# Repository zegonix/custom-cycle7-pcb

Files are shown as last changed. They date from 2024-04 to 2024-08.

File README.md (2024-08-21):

This repository holds the design sources for a custom PCB and plate for the cycle 7 by TKD. I ordered a prototype and got that working but I do not guarantee anything.

***Note that I used a 12 MHz oscillator instead of an 8 MHz which would be QMKs default frequency for the STM32F401. That is no problem, but requires a little extra configuration. If you don't fancy that, change the oscillator circuit to 8 MHz.***

***Also the design replaces the standard 6.25u spacebar with a 1.25u key, a 2.75u key and a 2.25u key (in this order from the left). Very few keycap sets come with a 1.25 spacebar key, so you might want to change the design to use a different spacebar configuration. If you do that you also need to adjust the plate. If you plan to use the original plate of the cycle 7 you need to change the pcb design to a default 6.25u spacebar.***

Why make my own pcb for the cycle 7? Bootloader on TKD's PCB ~~is shit~~ does not comply with my requirements. Also the firmware is proprietary.

What about this PCB? Sources are here and free to use however you want. **However use at your own risk, I do not guarantee any of this to be functional**
The QMK configuration for the keyboard is available at [zegonix/zegonix-qmk-configs/zegonix/cycle7](https://github.com/zegonix/zegonix-qmk-configs). Follow the steps described in the readme file to link the folder into your local qmk repository and build the firmware.

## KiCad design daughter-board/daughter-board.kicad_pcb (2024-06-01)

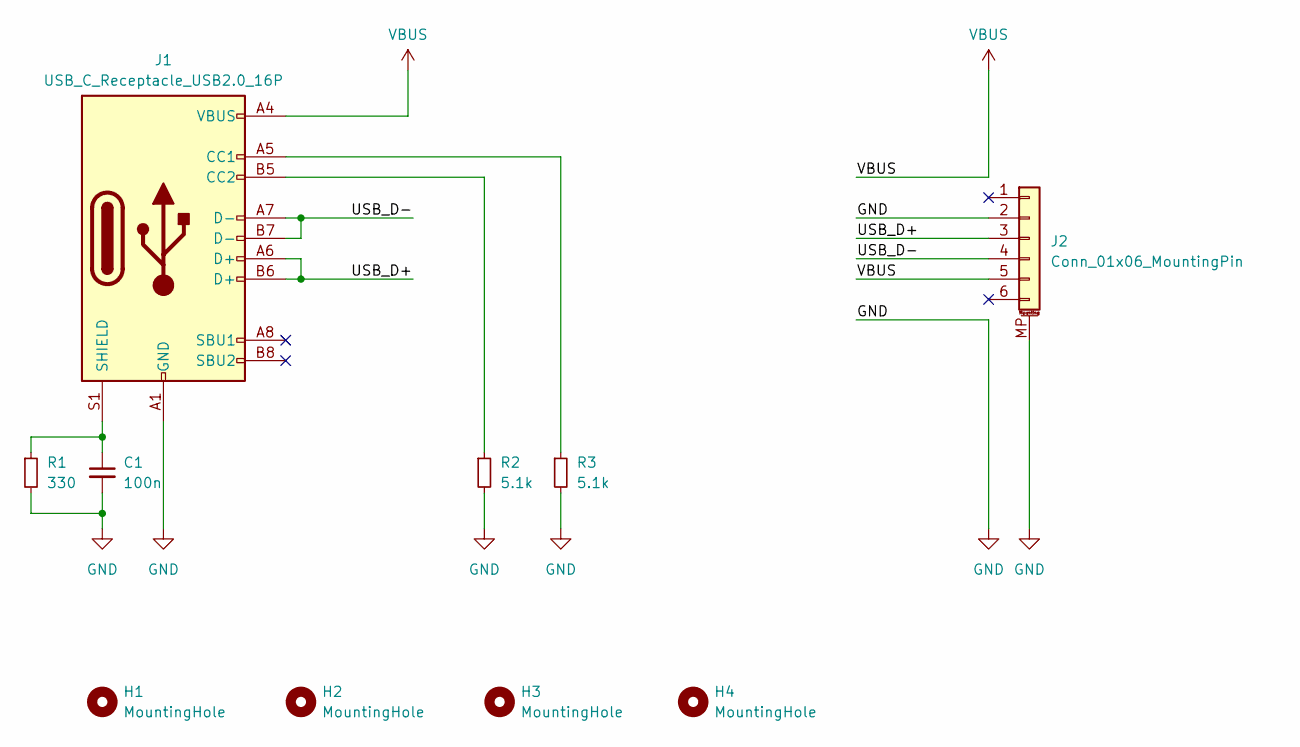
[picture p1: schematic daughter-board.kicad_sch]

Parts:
C1: 100n; C_0603_1608Metric
H1, H2, H3, H4: MountingHole; MountingHole_2.2mm_M2
J1: USB_C_Receptacle_USB2.0_16P; USB_C_Receptacle_HRO_TYPE-C-31-M-12
J2: Conn_01x06_MountingPin; JST_SH_SM06B-SRSS-TB_1x06-1MP_P1.00mm_Horizontal
R1: 330; R_0603_1608Metric
R2, R3: 5.1k; R_0603_1608Metric

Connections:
/USB_D+: J1.A6 (D+), J1.B6 (D+), J2.3
/USB_D-: J1.A7 (D-), J1.B7 (D-), J2.4
GND: C1.2, J1.A1 (GND), J1.A12 (GND), J1.B1 (GND), J1.B12 (GND), J2.2, J2.MP (MountPin), R1.2, R2.2, R3.2
unnamed: J1.A5 (CC1), R3.1
unnamed: J1.B5 (CC2), R2.1
unnamed: C1.1, J1.S1 (SHIELD), R1.1
VBUS: J1.A4 (VBUS), J1.A9 (VBUS), J1.B4 (VBUS), J1.B9 (VBUS), J2.5

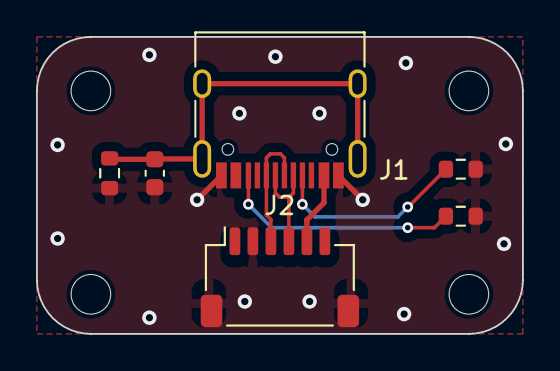
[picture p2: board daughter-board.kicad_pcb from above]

Board: 2 copper layers, 27.0 x 16.5 mm, 10 parts (0 on the bottom side), 7 nets.

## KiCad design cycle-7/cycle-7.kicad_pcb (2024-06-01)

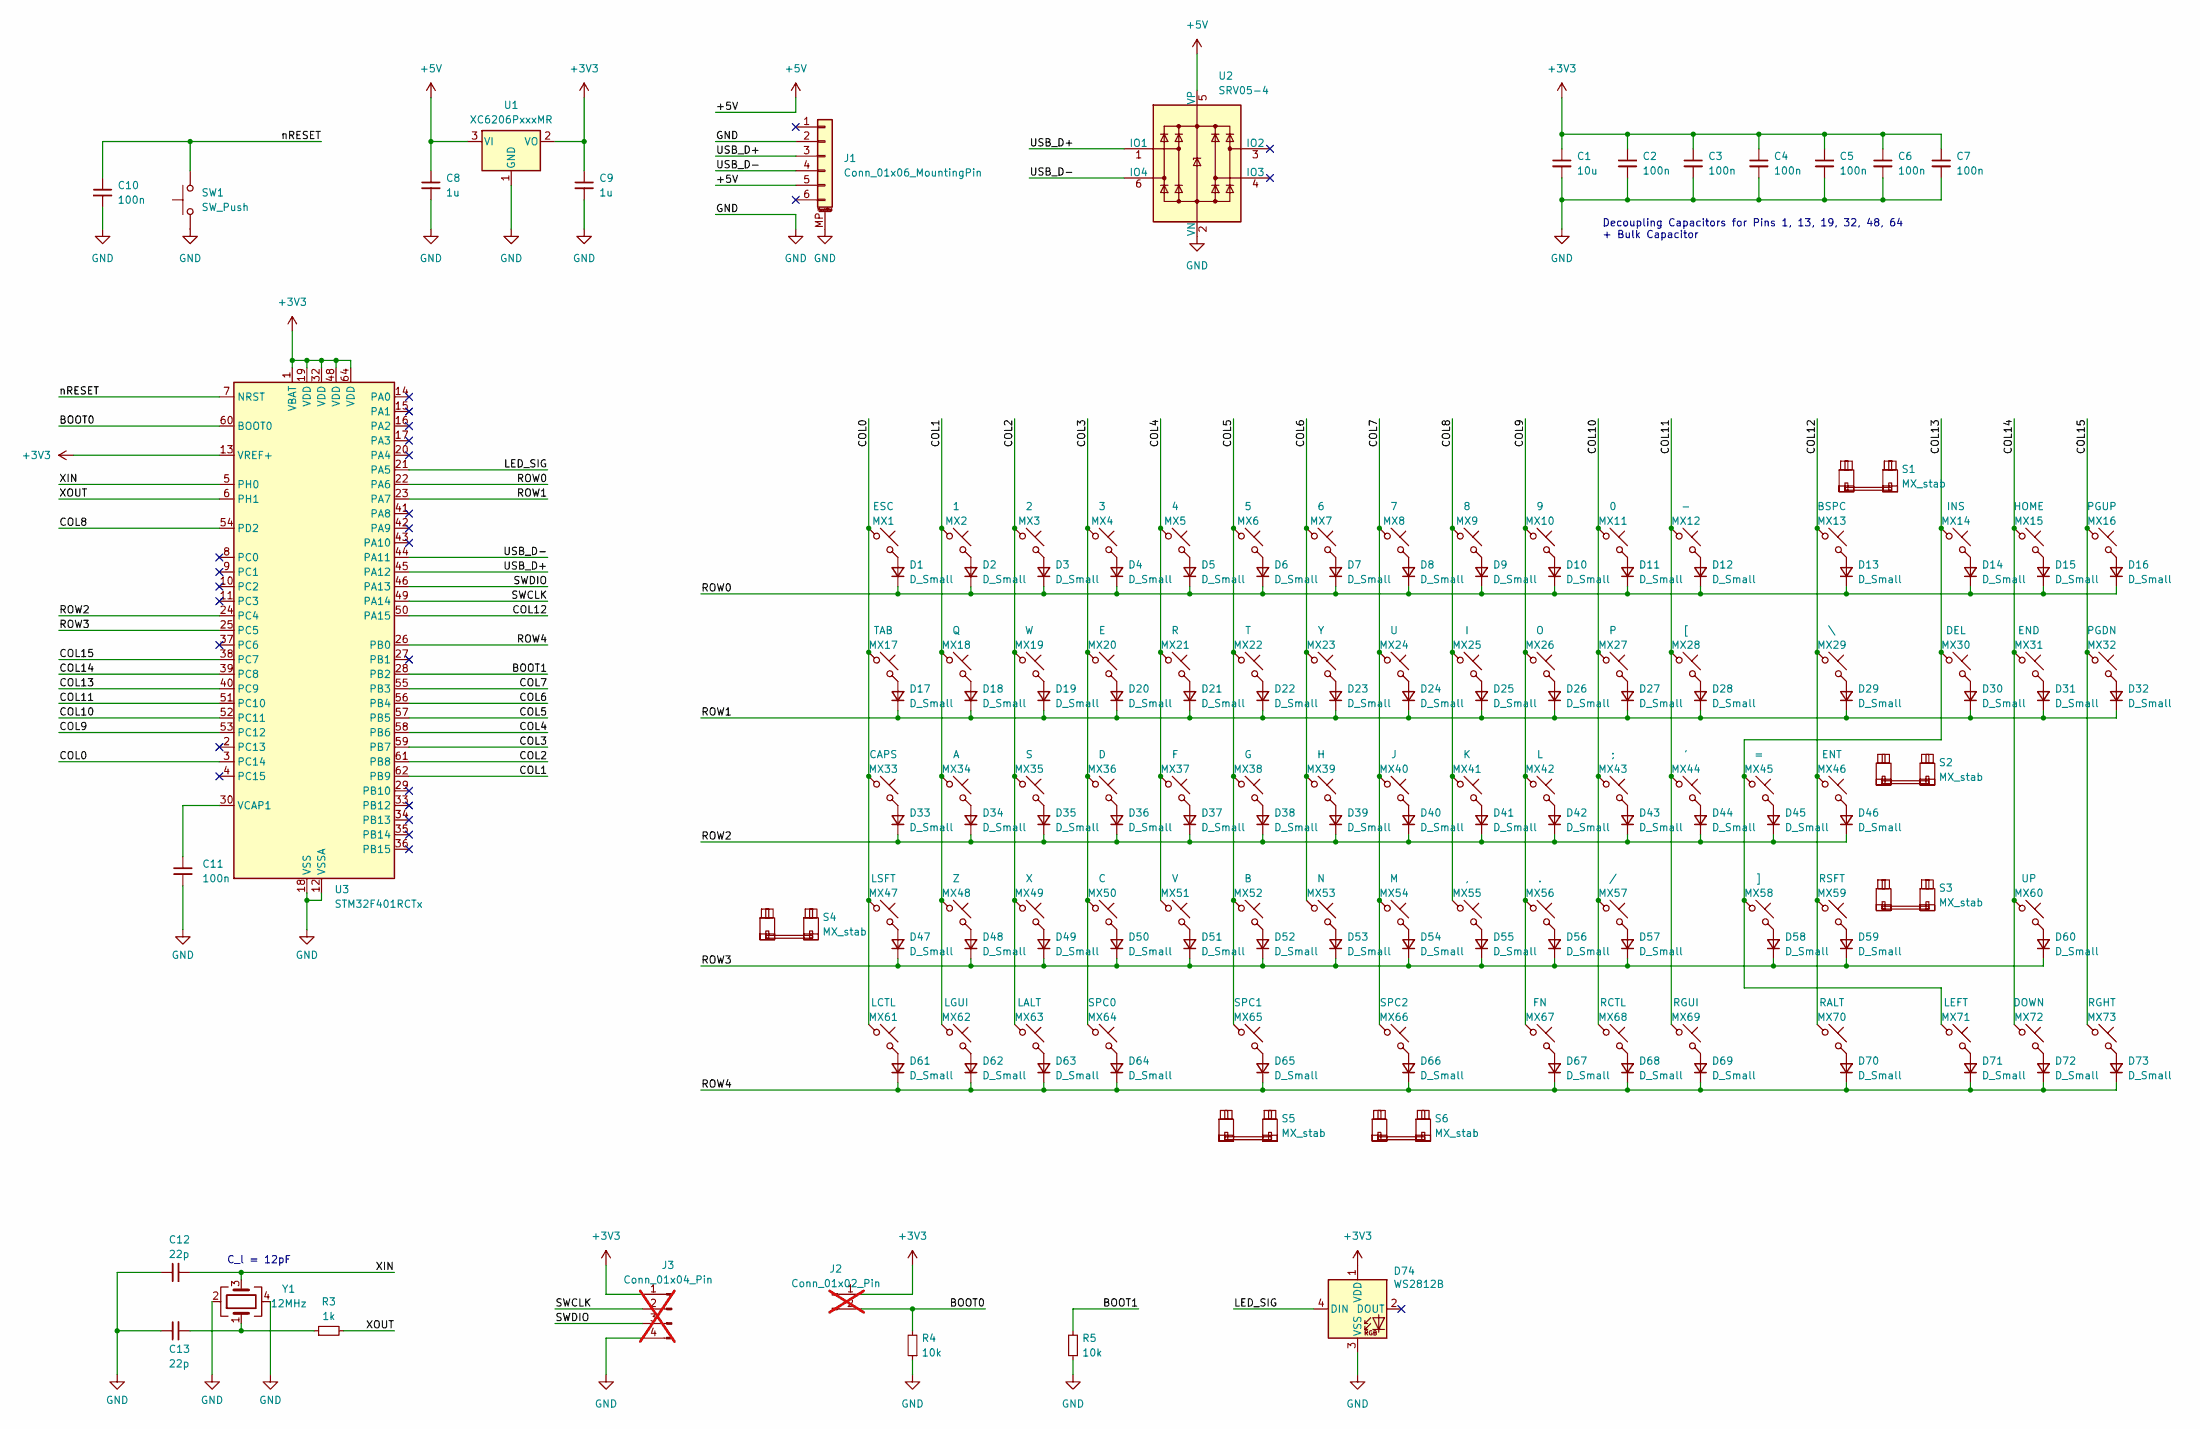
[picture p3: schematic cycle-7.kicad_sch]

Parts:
C1: 10u; C_0603_1608Metric
C2, C3, C4, C5, C6, C7, C10, C11: 100n; C_0603_1608Metric
C8, C9: 1u; C_0603_1608Metric
C12, C13: 22p; C_0603_1608Metric
D1, D2, D3, D4, D5, D6, D7, D8, D9, D10, D11, D12, D13, D14, D15, D16, D17, D18, D19, D20, D21, D22, D23, D24, D25, D26, D27, D28, D29, D30, D31, D32, D33, D34, D35, D36, D37, D38, D39, D40, D41, D42, D43, D44, D45, D46, D47, D48, D49, D50, D51, D52, D53, D54, D55, D56, D57, D58, D59, D60, D61, D62, D63, D64, D65, D66, D67, D68, D69, D70, D71, D72, D73: D_Small; D_SOD-123
D74: WS2812B; SK6812MINI-E_3.2x2.8_reverse_mount
J1: Conn_01x06_MountingPin; JST_SH_SM06B-SRSS-TB_1x06-1MP_P1.00mm_Horizontal
J2: Conn_01x02_Pin; PinHeader_1x02_P2.54mm_Vertical; not fitted
J3: Conn_01x04_Pin; PinHeader_1x04_P2.54mm_Vertical; not fitted
MX1, MX2, MX3, MX4, MX5, MX6, MX7, MX8, MX9, MX10, MX11, MX12, MX13, MX14, MX15, MX16, MX18, MX19, MX20, MX21, MX22, MX23, MX24, MX25, MX26, MX27, MX28, MX30, MX31, MX32, MX34, MX35, MX36, MX37, MX38, MX39, MX40, MX41, MX42, MX43, MX44, MX45, MX46, MX47, MX48, MX49, MX50, MX51, MX52, MX53, MX54, MX55, MX56, MX57, MX58, MX59, MX60, MX65, MX66, MX71, MX72, MX73: MX_SW_HS; SW_MX_HS_1u
MX17, MX29: MX_SW_HS; SW_MX_HS_1.5u
MX33: MX_SW_HS; SW_MX_HS_1.75u
MX61, MX62, MX63, MX64, MX67, MX68, MX69, MX70: MX_SW_HS; SW_MX_HS_1.25u
R3: 1k; R_0603_1608Metric
R4, R5: 10k; R_0603_1608Metric
S1: MX_stab; STAB_MX_P_2u
S2, S4, S6: MX_stab; STAB_MX_P_2.25u
S3, S5: MX_stab; STAB_MX_P_2.75u
SW1: SW_Push; SW_SPST_TL3342
U1: XC6206PxxxMR; SOT-23-3
U2: SRV05-4; SOT-23-6-routable
U3: STM32F401RCTx; LQFP-64_10x10mm_P0.5mm
Y1: 12MHz; Crystal_SMD_3225-4Pin_3.2x2.5mm

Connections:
+3V3: C1.1, C2.1, C3.1, C4.1, C5.1, C6.1, C7.1, C9.1, D74.1 (VDD), J2.1, J3.1, U1.2 (VO), U3.1 (VBAT), U3.13 (VREF+), U3.19 (VDD), U3.32 (VDD), U3.48 (VDD), U3.64 (VDD)
+5V: C8.1, J1.5, U1.3 (VI), U2.5 (VP)
/BOOT0: J2.2, R4.2, U3.60 (BOOT0)
/BOOT1: R5.2, U3.28 (PB2)
/COL0: MX1.1, MX17.1, MX33.1, MX47.1, MX61.1, U3.3 (PC14)
/COL1: MX2.1, MX18.1, MX34.1, MX48.1, MX62.1, U3.62 (PB9)
/COL2: MX3.1, MX19.1, MX35.1, MX49.1, MX63.1, U3.61 (PB8)
/COL3: MX4.1, MX20.1, MX36.1, MX50.1, MX64.1, U3.59 (PB7)
/COL4: MX5.1, MX21.1, MX37.1, MX51.1, U3.58 (PB6)
/COL5: MX6.1, MX22.1, MX38.1, MX52.1, MX65.1, U3.57 (PB5)
/COL6: MX7.1, MX23.1, MX39.1, MX53.1, U3.56 (PB4)
/COL7: MX8.1, MX24.1, MX40.1, MX54.1, MX66.1, U3.55 (PB3)
/COL8: MX9.1, MX25.1, MX41.1, MX55.1, U3.54 (PD2)
/COL9: MX10.1, MX26.1, MX42.1, MX56.1, MX67.1, U3.53 (PC12)
/COL10: MX11.1, MX27.1, MX43.1, MX57.1, MX68.1, U3.52 (PC11)
/COL11: MX12.1, MX28.1, MX44.1, MX69.1, U3.51 (PC10)
/COL12: MX13.1, MX29.1, MX46.1, MX59.1, MX70.1, U3.50 (PA15)
/COL13: MX14.1, MX30.1, MX45.1, MX58.1, MX71.1, U3.40 (PC9)
/COL14: MX15.1, MX31.1, MX60.1, MX72.1, U3.39 (PC8)
/COL15: MX16.1, MX32.1, MX73.1, U3.38 (PC7)
/LED_SIG: D74.4 (DIN), U3.21 (PA5)
/ROW0: D1.1 (K), D2.1 (K), D3.1 (K), D4.1 (K), D5.1 (K), D6.1 (K), D7.1 (K), D8.1 (K), D9.1 (K), D10.1 (K), D11.1 (K), D12.1 (K), D13.1 (K), D14.1 (K), D15.1 (K), D16.1 (K), U3.22 (PA6)
/ROW1: D17.1 (K), D18.1 (K), D19.1 (K), D20.1 (K), D21.1 (K), D22.1 (K), D23.1 (K), D24.1 (K), D25.1 (K), D26.1 (K), D27.1 (K), D28.1 (K), D29.1 (K), D30.1 (K), D31.1 (K), D32.1 (K), U3.23 (PA7)
/ROW2: D33.1 (K), D34.1 (K), D35.1 (K), D36.1 (K), D37.1 (K), D38.1 (K), D39.1 (K), D40.1 (K), D41.1 (K), D42.1 (K), D43.1 (K), D44.1 (K), D45.1 (K), D46.1 (K), U3.24 (PC4)
/ROW3: D47.1 (K), D48.1 (K), D49.1 (K), D50.1 (K), D51.1 (K), D52.1 (K), D53.1 (K), D54.1 (K), D55.1 (K), D56.1 (K), D57.1 (K), D58.1 (K), D59.1 (K), D60.1 (K), U3.25 (PC5)
/ROW4: D61.1 (K), D62.1 (K), D63.1 (K), D64.1 (K), D65.1 (K), D66.1 (K), D67.1 (K), D68.1 (K), D69.1 (K), D70.1 (K), D71.1 (K), D72.1 (K), D73.1 (K), U3.26 (PB0)
/SWCLK: J3.2, U3.49 (PA14)
/SWDIO: J3.3, U3.46 (PA13)
/USB_D+: J1.3, U2.1 (IO1), U3.45 (PA12)
/USB_D-: J1.4, U2.6 (IO4), U3.44 (PA11)
/XIN: C12.2, U3.5 (PH0), Y1.3
/XOUT: R3.2, U3.6 (PH1)
/nRESET: C10.1, SW1.2, U3.7 (NRST)
GND: C1.2, C2.2, C3.2, C4.2, C5.2, C6.2, C7.2, C8.2, C9.2, C10.2, C11.2, C12.1, C13.1, D74.3 (VSS), J1.2, J1.MP (MountPin), J3.4, R4.1, R5.1, SW1.1, U1.1 (GND), U2.2 (VN), U3.12 (VSSA), U3.18 (VSS), U3.31 (VSS), U3.47 (VSS), U3.63 (VSS), Y1.2, Y1.4
unnamed: C13.2, R3.1, Y1.1
unnamed: D1.2 (A), MX1.2
unnamed: D2.2 (A), MX2.2
unnamed: D3.2 (A), MX3.2
unnamed: D4.2 (A), MX4.2
unnamed: D5.2 (A), MX5.2
unnamed: D6.2 (A), MX6.2
unnamed: D7.2 (A), MX7.2
unnamed: D8.2 (A), MX8.2
unnamed: D9.2 (A), MX9.2
unnamed: D10.2 (A), MX10.2
unnamed: D11.2 (A), MX11.2
unnamed: D12.2 (A), MX12.2
unnamed: D13.2 (A), MX13.2
unnamed: D14.2 (A), MX14.2
unnamed: D15.2 (A), MX15.2
unnamed: D16.2 (A), MX16.2
unnamed: D17.2 (A), MX17.2
unnamed: D18.2 (A), MX18.2
unnamed: D19.2 (A), MX19.2
unnamed: D20.2 (A), MX20.2
unnamed: D21.2 (A), MX21.2
unnamed: D22.2 (A), MX22.2
unnamed: D23.2 (A), MX23.2
unnamed: D24.2 (A), MX24.2
unnamed: D25.2 (A), MX25.2
unnamed: D26.2 (A), MX26.2
unnamed: D27.2 (A), MX27.2
unnamed: D28.2 (A), MX28.2
unnamed: D29.2 (A), MX29.2
unnamed: D30.2 (A), MX30.2
unnamed: D31.2 (A), MX31.2
unnamed: D32.2 (A), MX32.2
unnamed: D33.2 (A), MX33.2
unnamed: D34.2 (A), MX34.2
unnamed: D35.2 (A), MX35.2
unnamed: D36.2 (A), MX36.2
unnamed: D37.2 (A), MX37.2
unnamed: D38.2 (A), MX38.2
unnamed: D39.2 (A), MX39.2
unnamed: D40.2 (A), MX40.2
unnamed: D41.2 (A), MX41.2
unnamed: D42.2 (A), MX42.2
unnamed: D43.2 (A), MX43.2
unnamed: D44.2 (A), MX44.2
unnamed: D45.2 (A), MX45.2
unnamed: D46.2 (A), MX46.2
unnamed: D47.2 (A), MX47.2
unnamed: D48.2 (A), MX48.2
unnamed: D49.2 (A), MX49.2
unnamed: D50.2 (A), MX50.2
unnamed: D51.2 (A), MX51.2
unnamed: D52.2 (A), MX52.2
unnamed: D53.2 (A), MX53.2
unnamed: D54.2 (A), MX54.2
unnamed: D55.2 (A), MX55.2
unnamed: D56.2 (A), MX56.2
unnamed: D57.2 (A), MX57.2
unnamed: D58.2 (A), MX58.2
unnamed: D59.2 (A), MX59.2
unnamed: D60.2 (A), MX60.2
unnamed: D61.2 (A), MX61.2
unnamed: D62.2 (A), MX62.2
unnamed: D63.2 (A), MX63.2
unnamed: D64.2 (A), MX64.2
unnamed: D65.2 (A), MX65.2
unnamed: D66.2 (A), MX66.2
unnamed: D67.2 (A), MX67.2
unnamed: D68.2 (A), MX68.2
unnamed: D69.2 (A), MX69.2
unnamed: D70.2 (A), MX70.2
unnamed: D71.2 (A), MX71.2
unnamed: D72.2 (A), MX72.2
unnamed: D73.2 (A), MX73.2
unnamed: C11.1, U3.30 (VCAP1)

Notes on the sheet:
Decoupling Capacitors for Pins 1, 13, 19, 32, 48, 64 + Bulk Capacitor
C_l = 12pF

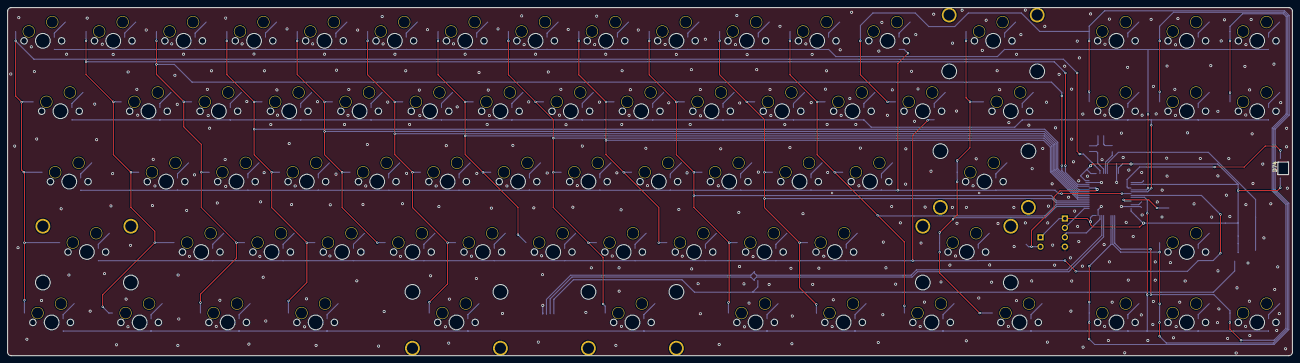
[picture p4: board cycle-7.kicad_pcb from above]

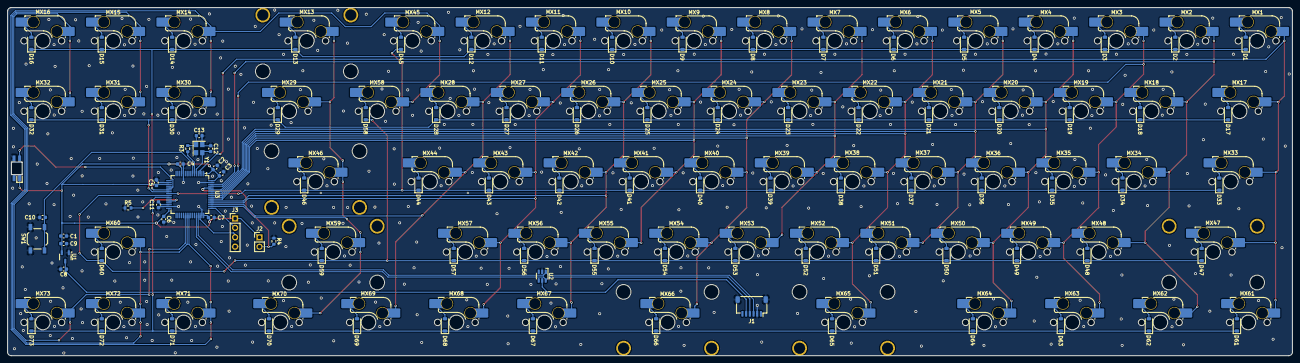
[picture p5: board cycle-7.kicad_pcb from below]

Board: 2 copper layers, 347.7 x 94.2 mm, 177 parts (170 on the bottom side), 109 nets.

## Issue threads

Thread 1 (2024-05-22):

JLCPCB CPL Issue

Alethi94, 2024-05-22:
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

Hi,
just want to say thanks for creating a PCB for the cycle7, mine seems to have some chatter and there's no extras about so this will be great!

When importing into JLCPCB, it is throwing the above error regarding the CPL list.

could you advise on what it may be?

zegonix, 2024-05-24:
Hi Alethi

Short answer: this is expected, the Bill of Materials (BOM) is not up to date. For my prototypes I edited the BOM on JLCPCB's website.

This is partly on me, for not adding a readme yet, but this repository is work in progress and unless I make a release I do not take responsibility for potential harm or grieve these sources could cause.

If I remember, I will contact you, once I get the PCB running. Currently I can flash firmware via DFU in Bootloadermode, but the firmware can't seem to connect to the host pc, rendering the PCB useless. If you still want to order the PCB, you can download JLCPCB's example BOM and copy the entries to get a BOM their website accepts. I would advise against that though, as the PCB is not functional at the moment.

Best regards, zegonix

zegonix, 2024-06-01:
I managed to get the board working and updated my findings from the prototype. I did not update the bill of materials, as the vendors stocks are changing frequently.
You might want to change the design to use the standard 6.25u spacebar design instead of my weird split spacebar (1.25/2.75/2.25). Also consider changing the oscillator circuit to a frequency of 8 MHz, as that is QMKs default for the chip used and a different frequency requires extra configuration. I will provide a link to my configuration in this repositories readme soon though.

Best regards, zegonix

Closed 2024-06-01.

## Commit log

2024-04-14 fixed layout, added gnd plane stitching
    [cycle-7.kicad_pcb, cycle-7.kicad_sch]
2024-04-27 added a kicad project for the plate added a kicad project for the daughter board
    [cycle-7-B_Cu.gbr, cycle-7-B_Mask.gbr, cycle-7-B_Paste.gbr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]
2024-05-14 implemented newest findings from prototype and updated to kicad 8
    [cycle-7.kicad_pcb, cycle-7.kicad_sch]
2024-05-16 minor fixes
    [cycle-7.kicad_sch]
2024-05-24 added a readme, fixed kicad update mess..
    [cycle-7.kicad_pcb, cycle-7.kicad_sch]
2024-06-01 updated findings from prototype removed output folder as the vendors stock is everchanging
    [cycle-7-B_Cu.gbr, cycle-7-B_Mask.gbr, cycle-7-B_Paste.gbr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]
